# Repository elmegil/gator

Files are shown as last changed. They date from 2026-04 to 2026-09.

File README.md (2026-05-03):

"Hook's Gator" trigger (gate) sequencer.

Controls:
- tempo
- gate width (need to state range)
- step count
- swing (50% - no swing, to 70%)
- run/stop switch and gate input
- forward/backward (need to test backward with swing) switch and gate input
- reset button and gate input
- clock in + clock out (external clock is reflected on the output and overrides internal tempo)
- 1x16 or 2x8 operation -- in 1x16 both outputs reflect the same
- each step has a switch that indicates if there should be a gate out on that step or not.

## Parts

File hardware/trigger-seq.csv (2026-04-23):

Reference | Value | Footprint | Datasheet
P1 | CONN_02X05 | Connect:VASCH5x2
C2 | 10uF | Capacitors_ThroughHole:C_Radial_D5_L6_P2.5
C1 | 10uF | Capacitors_ThroughHole:C_Radial_D5_L6_P2.5
D2 | 1N4001 | Diodes_ThroughHole:Diode_DO-41_SOD81_Horizontal_RM10
D1 | 1N4001 | Diodes_ThroughHole:Diode_DO-41_SOD81_Horizontal_RM10
F2 | F_Small | Capacitors_ThroughHole:C_Disc_D7.5_P5
F1 | F_Small | Capacitors_ThroughHole:C_Disc_D7.5_P5
C3 | 100n | Capacitors_ThroughHole:C_Rect_L7_W2_P5
C5 | 100n | Capacitors_ThroughHole:C_Rect_L7_W2_P5
C6 | 100n | Capacitors_ThroughHole:C_Rect_L7_W2_P5
C7 | 100n | Capacitors_ThroughHole:C_Rect_L7_W2_P5
P8 | CONN_01X04 | My Library:MTA-156-4
U1 | LM555N | Housings_DIP:DIP-8_W7.62mm_LongPads
R2 | 100R | Resistors_ThroughHole:Resistor_Horizontal_RM10mm
RV1 | 100K | Walter Resistors:trimmer_alps-rk09k1130ah1
R1 | 15K | Resistors_ThroughHole:Resistor_Horizontal_RM10mm
C9 | 22uF | Capacitors_ThroughHole:C_Radial_D5_L11_P2.5
C4 | 100nF | Capacitors_ThroughHole:C_Rect_L7_W2_P5
U7 | TL072 | Housings_DIP:DIP-8_W7.62mm_LongPads
C8 | 100nF | Capacitors_ThroughHole:C_Rect_L7_W2_P5
C12 | 100nF | Capacitors_ThroughHole:C_Rect_L7_W2_P5
C10 | 100nF | Capacitors_ThroughHole:C_Rect_L7_W2_P5
C13 | 220uF | Capacitors_ThroughHole:C_Radial_D10_L13_P5
R3 | 4.7K | Resistors_ThroughHole:Resistor_Horizontal_RM10mm
R4 | 15K | Resistors_ThroughHole:Resistor_Horizontal_RM10mm
U8 | LM311N | Housings_DIP:DIP-8_W7.62mm_LongPads
C15 | 100nF | Capacitors_ThroughHole:C_Rect_L7_W2_P5
C14 | 100nF | Capacitors_ThroughHole:C_Rect_L7_W2_P5
R7 | 10K | Resistors_ThroughHole:Resistor_Horizontal_RM10mm
RV2 | 100K | Walter Resistors:trimmer_alps-rk09k1130ah1
R5 | 68K | Resistors_ThroughHole:Resistor_Horizontal_RM10mm
R6 | 82K | Resistors_ThroughHole:Resistor_Horizontal_RM10mm
P5 | CLOCK_MAIN | Pin_Headers:Pin_Header_Straight_2x02
P4 | CLOCK_PANEL | Socket_Strips:Socket_Strip_Straight_2x02
U2 | 4029 | Housings_DIP:DIP-16_W7.62mm_LongPads
J3 | DIRECTION | My Library:thonkiconn
SW2 | SWITCH_INV | Walter Switches:switch_100sp5
R11 | 100K | Resistors_ThroughHole:Resistor_Horizontal_RM10mm
D6 | D | Diodes_ThroughHole:Diode_DO-35_SOD27_Horizontal_RM10
Q5 | 2N3904 | TO_SOT_Packages_THT:TO-92_Inline_Narrow_Oval
R12 | 10K | Resistors_ThroughHole:Resistor_Horizontal_RM10mm
J2 | RESET | My Library:thonkiconn
SW1 | RESET | My Library:C&K_round_pushbutton
Q4 | 2N3904 | TO_SOT_Packages_THT:TO-92_Inline_Narrow_Oval
R8 | 100K | Resistors_ThroughHole:Resistor_Horizontal_RM10mm
D4 | D | Diodes_ThroughHole:Diode_DO-35_SOD27_Horizontal_RM10
R10 | 10K | Resistors_ThroughHole:Resistor_Horizontal_RM10mm
J1 | CLOCK_IN | My Library:thonkiconn
D5 | D | Diodes_ThroughHole:Diode_DO-35_SOD27_Horizontal_RM10
R9 | 100K | Resistors_ThroughHole:Resistor_Horizontal_RM10mm
U4 | 4051 | Housings_DIP:DIP-16_W7.62mm_LongPads
R16 | 10K | Resistors_ThroughHole:Resistor_Horizontal_RM10mm
U3 | 4051 | Housings_DIP:DIP-16_W7.62mm_LongPads
R15 | 10K | Resistors_ThroughHole:Resistor_Horizontal_RM10mm
Q6 | 2N3904 | TO_SOT_Packages_THT:TO-92_Inline_Narrow_Oval
R14 | 10K | Resistors_ThroughHole:Resistor_Horizontal_RM10mm
R13 | 10K | Resistors_ThroughHole:Resistor_Horizontal_RM10mm
SW3 | 3PDT | My Library:3PDT
C11 | 22n | Capacitors_ThroughHole:C_Rect_L7_W2_P5
P6 | SWITCH_PANEL | Socket_Strips:Socket_Strip_Straight_2x08
P7 | SWITCH_MAIN | Pin_Headers:Pin_Header_Straight_2x08
P2 | COUNT_PANEL | Socket_Strips:Socket_Strip_Straight_2x05
P3 | COUNT_MAIN | Pin_Headers:Pin_Header_Straight_2x05
D3 | 1N4148 | Diodes_ThroughHole:Diode_DO-35_SOD27_Horizontal_RM10
C16 | 810nF | Capacitors_ThroughHole:C_Rect_L7_W2_P5
R41 | 100K | Resistors_ThroughHole:Resistor_Horizontal_RM10mm
D7 | S1 | LEDs:LED-5MM
SW4 | SWITCH_INV | Walter Switches:switch_100sp5
D15 | 1N914 | Diodes_ThroughHole:Diode_DO-35_SOD27_Horizontal_RM10
J4 | OUT 1 | My Library:thonkiconn
SW5 | SWITCH_INV | Walter Switches:switch_100sp5
SW6 | SWITCH_INV | Walter Switches:switch_100sp5
SW7 | SWITCH_INV | Walter Switches:switch_100sp5
SW8 | SWITCH_INV | Walter Switches:switch_100sp5
SW9 | SWITCH_INV | Walter Switches:switch_100sp5
SW10 | SWITCH_INV | Walter Switches:switch_100sp5
SW11 | SWITCH_INV | Walter Switches:switch_100sp5
SW12 | SWITCH_INV | Walter Switches:switch_100sp5
SW13 | SWITCH_INV | Walter Switches:switch_100sp5
SW14 | SWITCH_INV | Walter Switches:switch_100sp5
SW15 | SWITCH_INV | Walter Switches:switch_100sp5
SW16 | SWITCH_INV | Walter Switches:switch_100sp5
SW17 | SWITCH_INV | Walter Switches:switch_100sp5
SW18 | SWITCH_INV | Walter Switches:switch_100sp5
SW19 | SWITCH_INV | Walter Switches:switch_100sp5
D16 | 1N914 | Diodes_ThroughHole:Diode_DO-35_SOD27_Horizontal_RM10
D17 | 1N914 | Diodes_ThroughHole:Diode_DO-35_SOD27_Horizontal_RM10
D18 | 1N914 | Diodes_ThroughHole:Diode_DO-35_SOD27_Horizontal_RM10
D19 | 1N914 | Diodes_ThroughHole:Diode_DO-35_SOD27_Horizontal_RM10
D20 | 1N914 | Diodes_ThroughHole:Diode_DO-35_SOD27_Horizontal_RM10
D21 | 1N914 | Diodes_ThroughHole:Diode_DO-35_SOD27_Horizontal_RM10
D22 | 1N914 | Diodes_ThroughHole:Diode_DO-35_SOD27_Horizontal_RM10
D38 | 1N914 | Diodes_ThroughHole:Diode_DO-35_SOD27_Horizontal_RM10
D37 | 1N914 | Diodes_ThroughHole:Diode_DO-35_SOD27_Horizontal_RM10
D36 | 1N914 | Diodes_ThroughHole:Diode_DO-35_SOD27_Horizontal_RM10
D35 | 1N914 | Diodes_ThroughHole:Diode_DO-35_SOD27_Horizontal_RM10
D34 | 1N914 | Diodes_ThroughHole:Diode_DO-35_SOD27_Horizontal_RM10
D33 | 1N914 | Diodes_ThroughHole:Diode_DO-35_SOD27_Horizontal_RM10
D32 | 1N914 | Diodes_ThroughHole:Diode_DO-35_SOD27_Horizontal_RM10
D31 | 1N914 | Diodes_ThroughHole:Diode_DO-35_SOD27_Horizontal_RM10
J5 | OUT 2 | My Library:thonkiconn
R34 | 1K | Resistors_ThroughHole:Resistor_Horizontal_RM10mm
R25 | 1K | Resistors_ThroughHole:Resistor_Horizontal_RM10mm
R17 | 1K | Resistors_ThroughHole:Resistor_Horizontal_RM10mm
D8 | S2 | LEDs:LED-5MM
R18 | 1K | Resistors_ThroughHole:Resistor_Horizontal_RM10mm
D9 | S3 | LEDs:LED-5MM
R19 | 1K | Resistors_ThroughHole:Resistor_Horizontal_RM10mm
D11 | S5 | LEDs:LED-5MM
R21 | 1K | Resistors_ThroughHole:Resistor_Horizontal_RM10mm
D12 | S6 | LEDs:LED-5MM
R22 | 1K | Resistors_ThroughHole:Resistor_Horizontal_RM10mm
D10 | S4 | LEDs:LED-5MM
R20 | 1K | Resistors_ThroughHole:Resistor_Horizontal_RM10mm
D13 | S7 | LEDs:LED-5MM
R23 | 1K | Resistors_ThroughHole:Resistor_Horizontal_RM10mm
D14 | S8 | LEDs:LED-5MM
R24 | 1K | Resistors_ThroughHole:Resistor_Horizontal_RM10mm
D23 | S9 | LEDs:LED-5MM
R26 | 1K | Resistors_ThroughHole:Resistor_Horizontal_RM10mm
D24 | S10 | LEDs:LED-5MM
R27 | 1K | Resistors_ThroughHole:Resistor_Horizontal_RM10mm
D25 | S11 | LEDs:LED-5MM
R28 | 1K | Resistors_ThroughHole:Resistor_Horizontal_RM10mm
D26 | S12 | LEDs:LED-5MM
R29 | 1K | Resistors_ThroughHole:Resistor_Horizontal_RM10mm
D27 | S13 | LEDs:LED-5MM
R30 | 1K | Resistors_ThroughHole:Resistor_Horizontal_RM10mm
D28 | S14 | LEDs:LED-5MM
R31 | 1K | Resistors_ThroughHole:Resistor_Horizontal_RM10mm
D29 | S15 | LEDs:LED-5MM
R32 | 1K | Resistors_ThroughHole:Resistor_Horizontal_RM10mm
D30 | S16 | LEDs:LED-5MM
R33 | 1K | Resistors_ThroughHole:Resistor_Horizontal_RM10mm
R38 | 10K | Resistors_ThroughHole:Resistor_Horizontal_RM10mm
R39 | 10K | Resistors_ThroughHole:Resistor_Horizontal_RM10mm
R36 | 10K | Resistors_ThroughHole:Resistor_Horizontal_RM10mm
Q7 | 2N3904 | TO_SOT_Packages_THT:TO-92_Inline_Narrow_Oval
R37 | 10K | Resistors_ThroughHole:Resistor_Horizontal_RM10mm
U5 | LM311N | Housings_DIP:DIP-8_W7.62mm_LongPads
U6 | LM311N | Housings_DIP:DIP-8_W7.62mm_LongPads
R35 | 10K | Resistors_ThroughHole:Resistor_Horizontal_RM10mm
R40 | 10K | Resistors_ThroughHole:Resistor_Horizontal_RM10mm
J6 | CLOCK_OUT | My Library:thonkiconn
R42 | 1K | Resistors_ThroughHole:Resistor_Horizontal_RM10mm

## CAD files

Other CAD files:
firmware/gator.X/l.obj

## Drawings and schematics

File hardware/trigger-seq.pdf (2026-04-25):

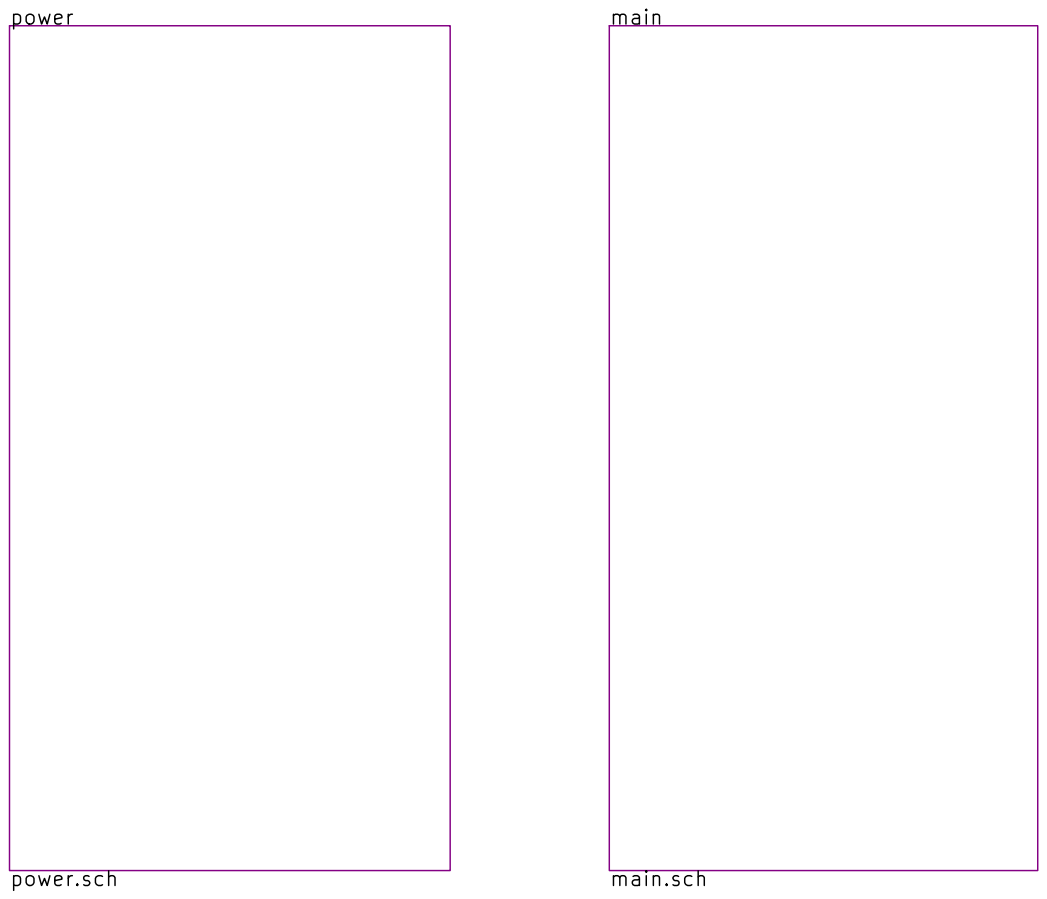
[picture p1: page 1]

simple trigger sequencer to go with the 808 boards
File: trigger-seq.sch Sheet: / Frogleg Synthesis

Id: 1/6 Title: Trigger Sequencer

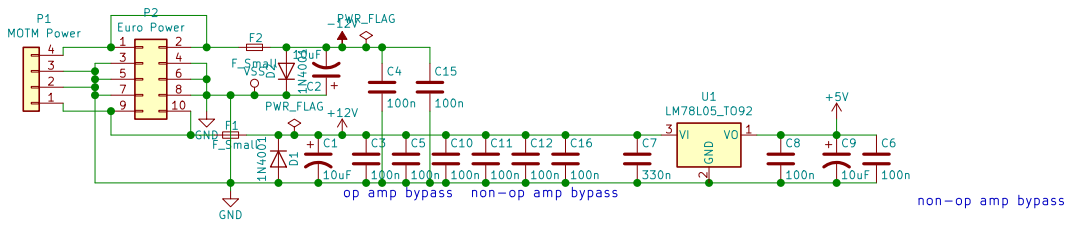
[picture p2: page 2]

100n non-op amp bypass C16

Frogleg Synthesis
Sheet: /power/
File: power.sch
Id: 2/6 Title: Voice Host

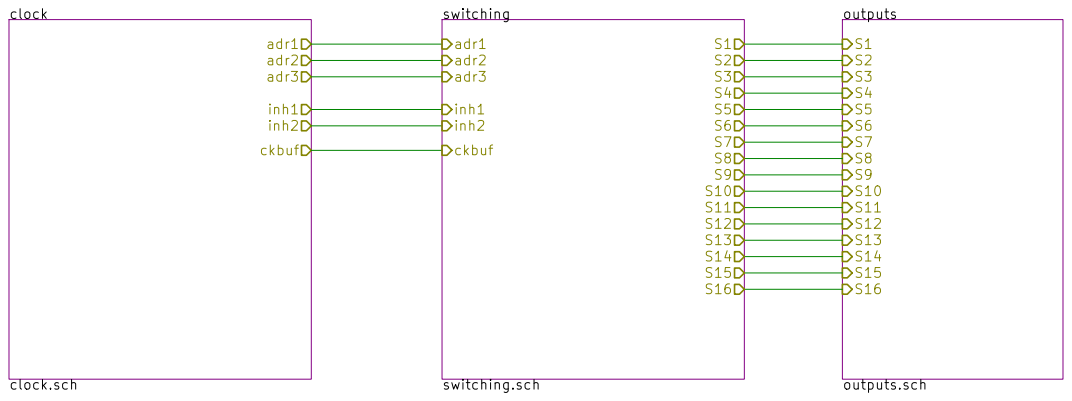
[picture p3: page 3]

Id: 3/6 Title: File: main.sch Sheet: /main/

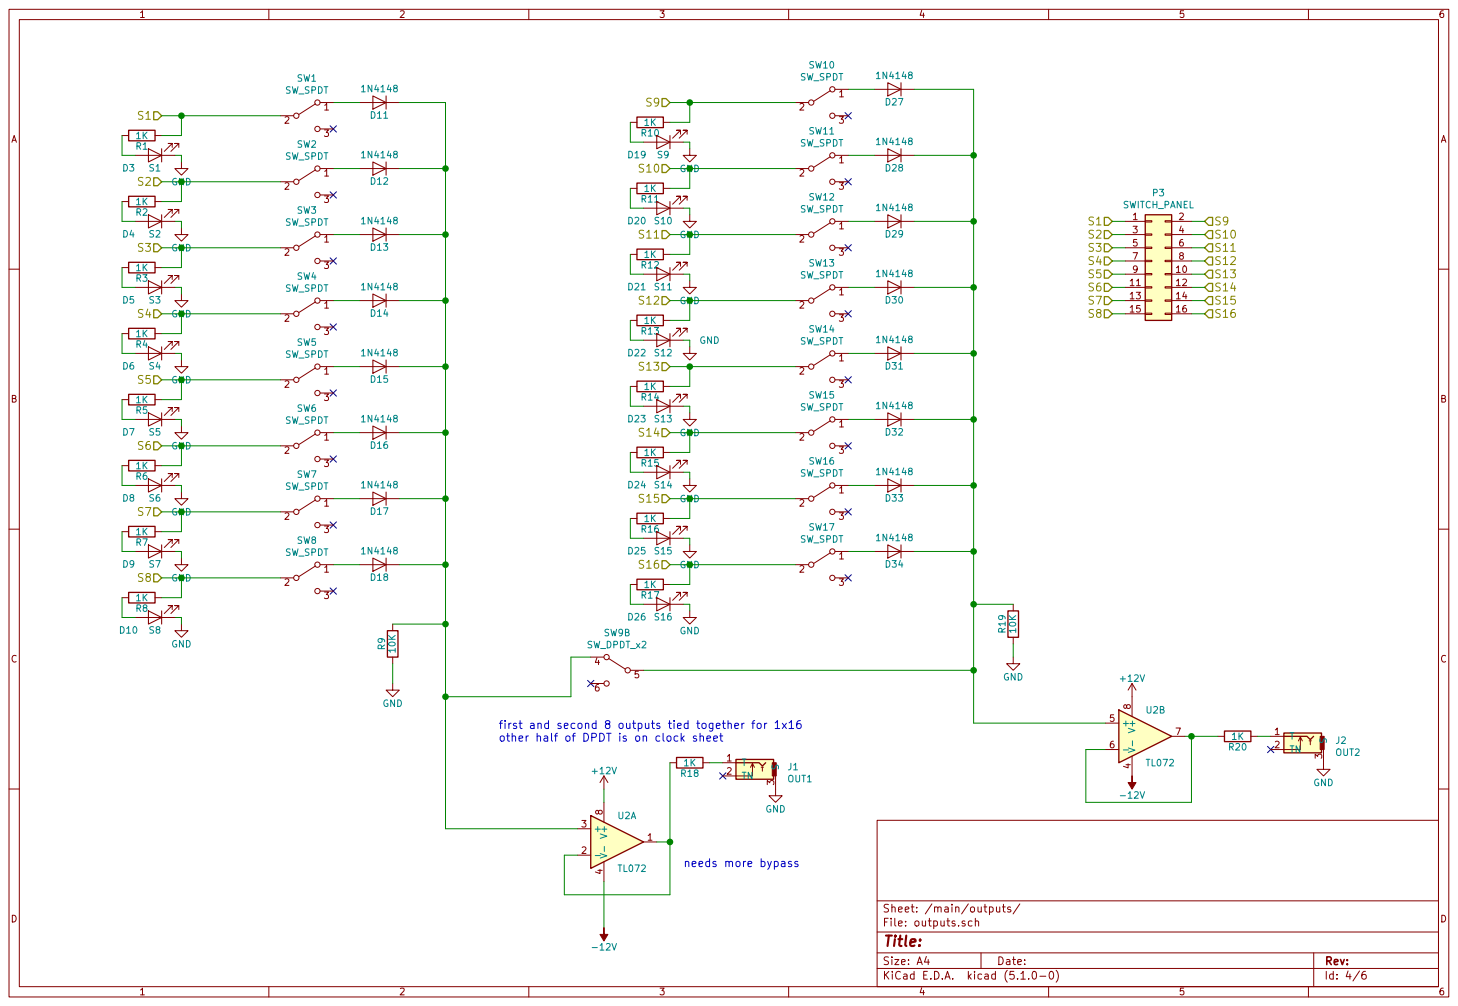
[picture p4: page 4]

first and second 8 outputs tied together for 1x16 other half of DPDT is on clock sheet

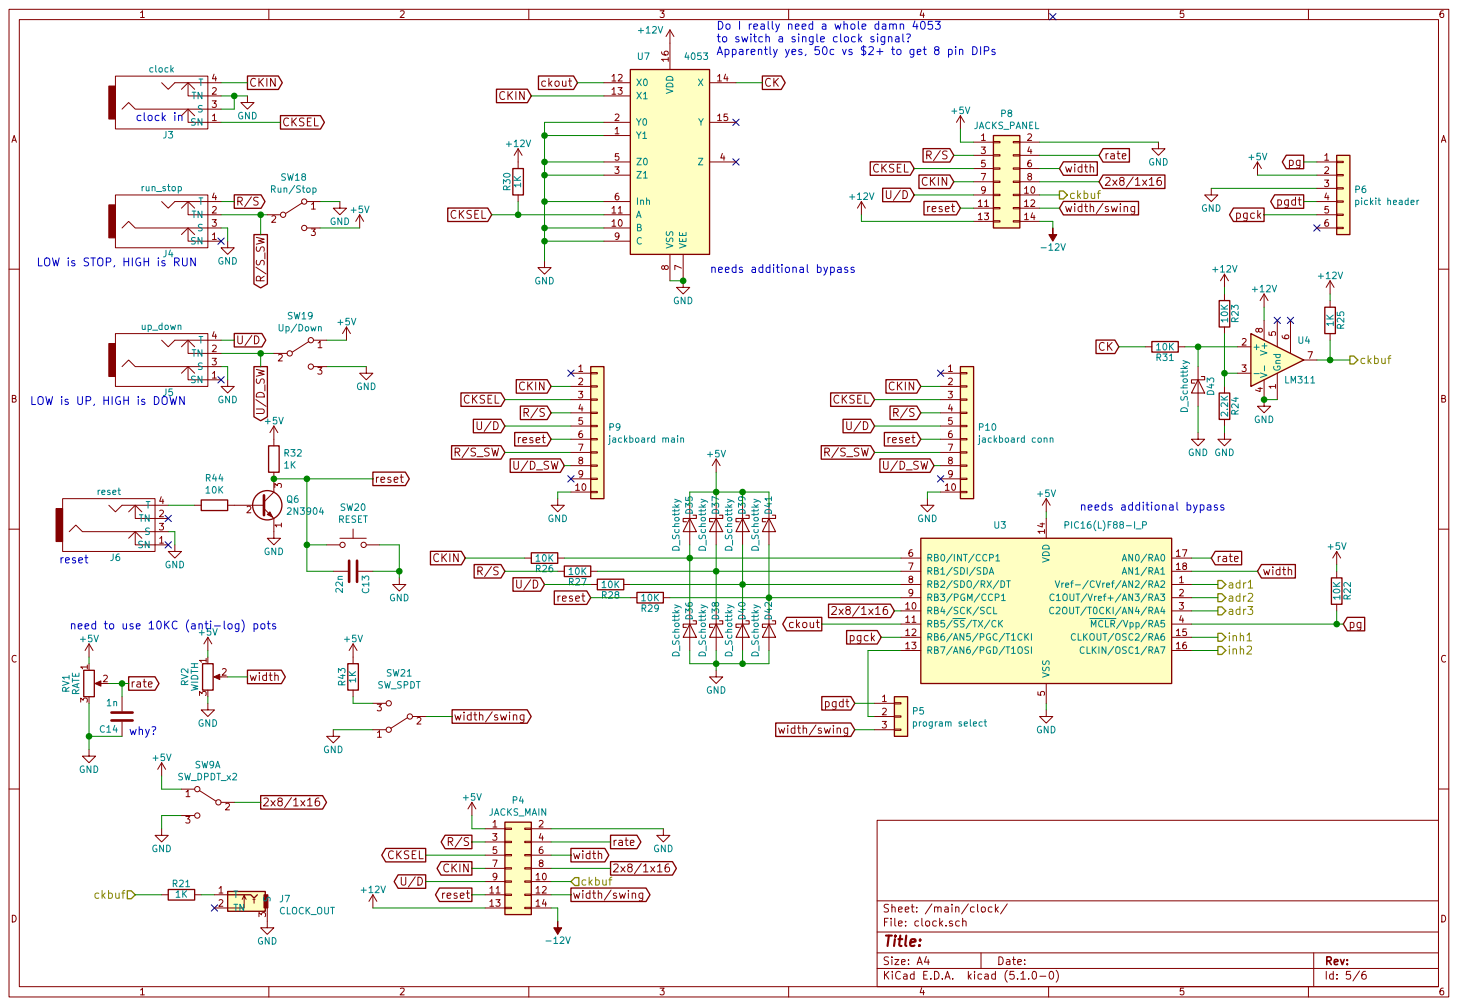
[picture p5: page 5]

+5V Do I really need a whole damn 4053
to switch a single clock signal?

Apparently yes, 50c vs $2+ to get 8 pin DIPs GND

LOW is STOP, HIGH is RUN

LOW is UP, HIGH is DOWN

5 RB0/INT/CCP1 6 RB1/SDI/SDA 7 RB2/SDO/RX/DT 8 RB3/PGM/CCP1 9 U3 PIC16(L)F88-I_P

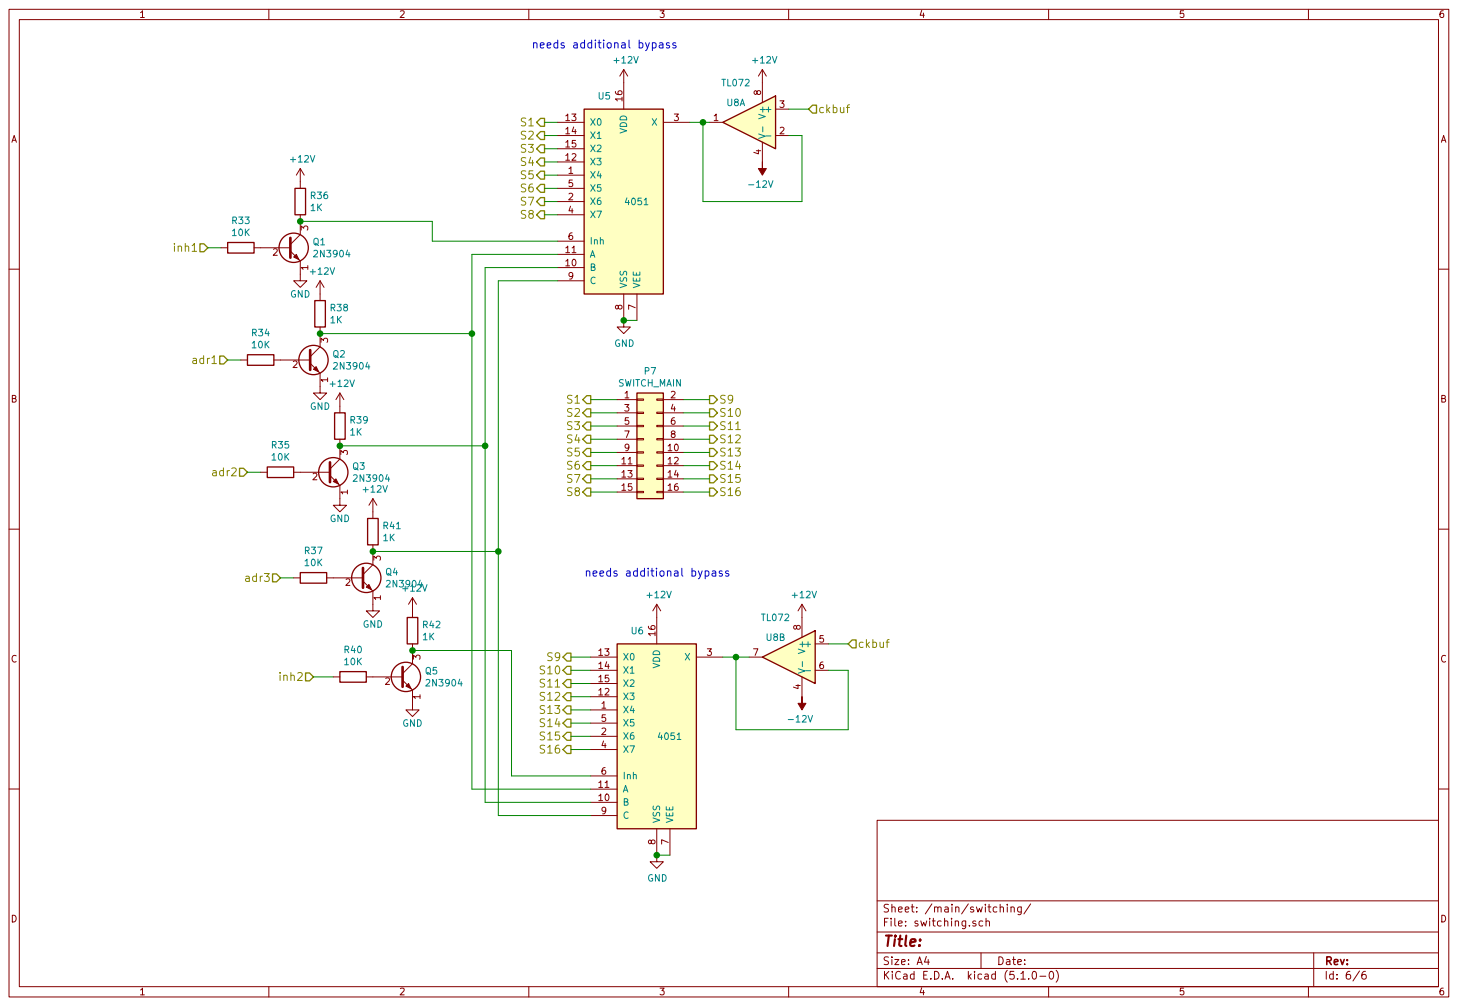
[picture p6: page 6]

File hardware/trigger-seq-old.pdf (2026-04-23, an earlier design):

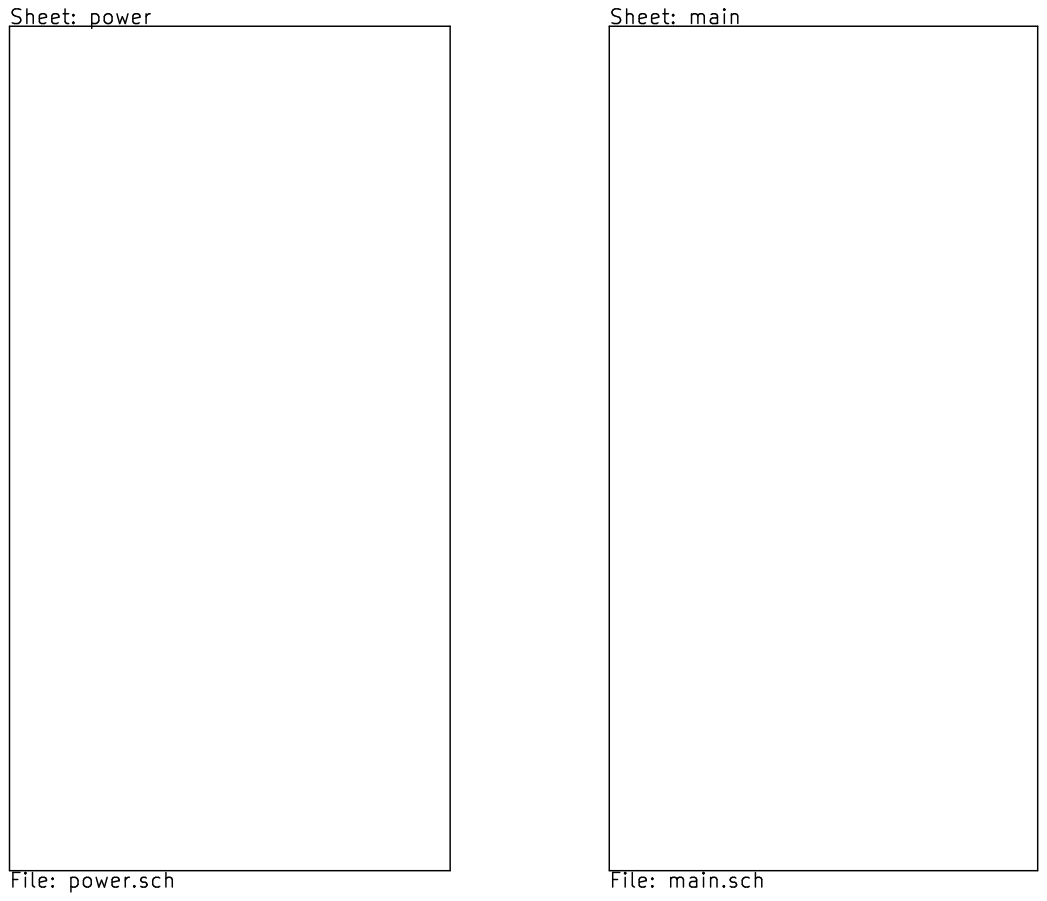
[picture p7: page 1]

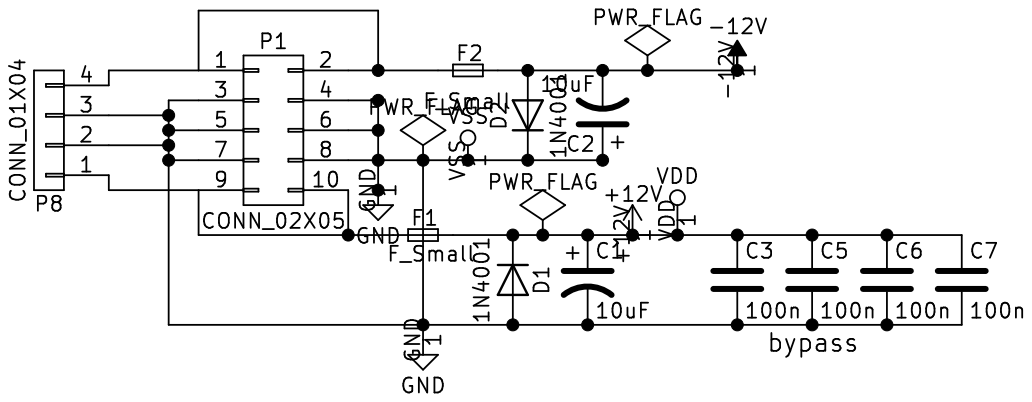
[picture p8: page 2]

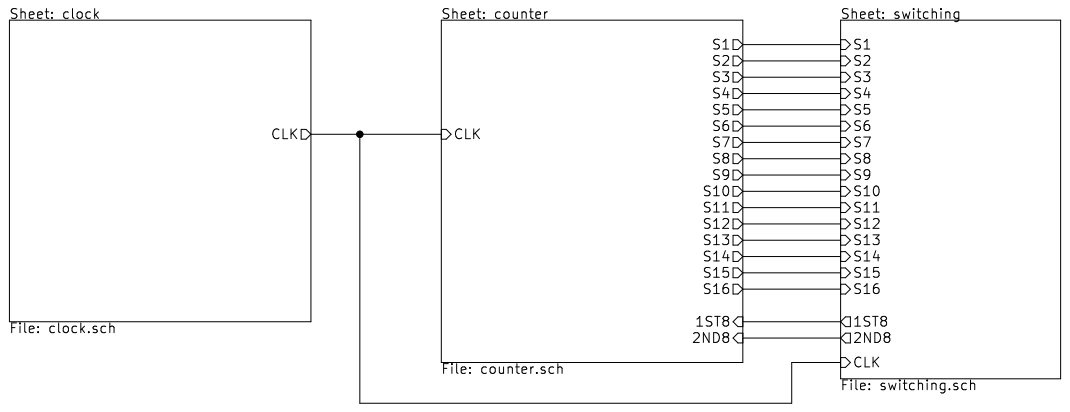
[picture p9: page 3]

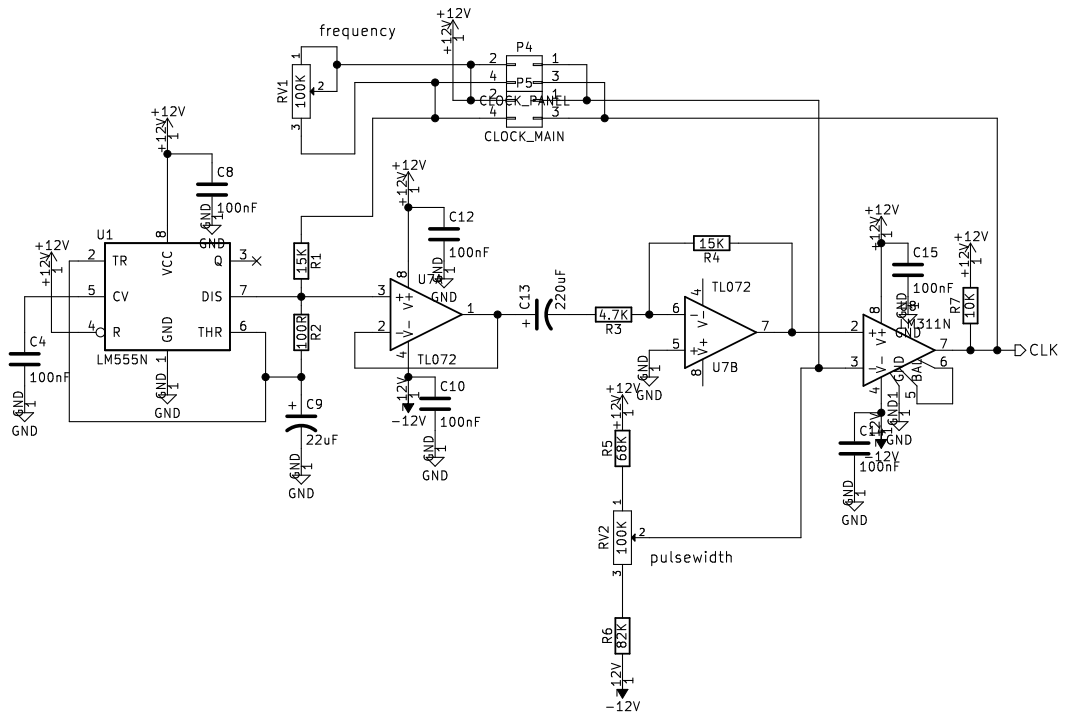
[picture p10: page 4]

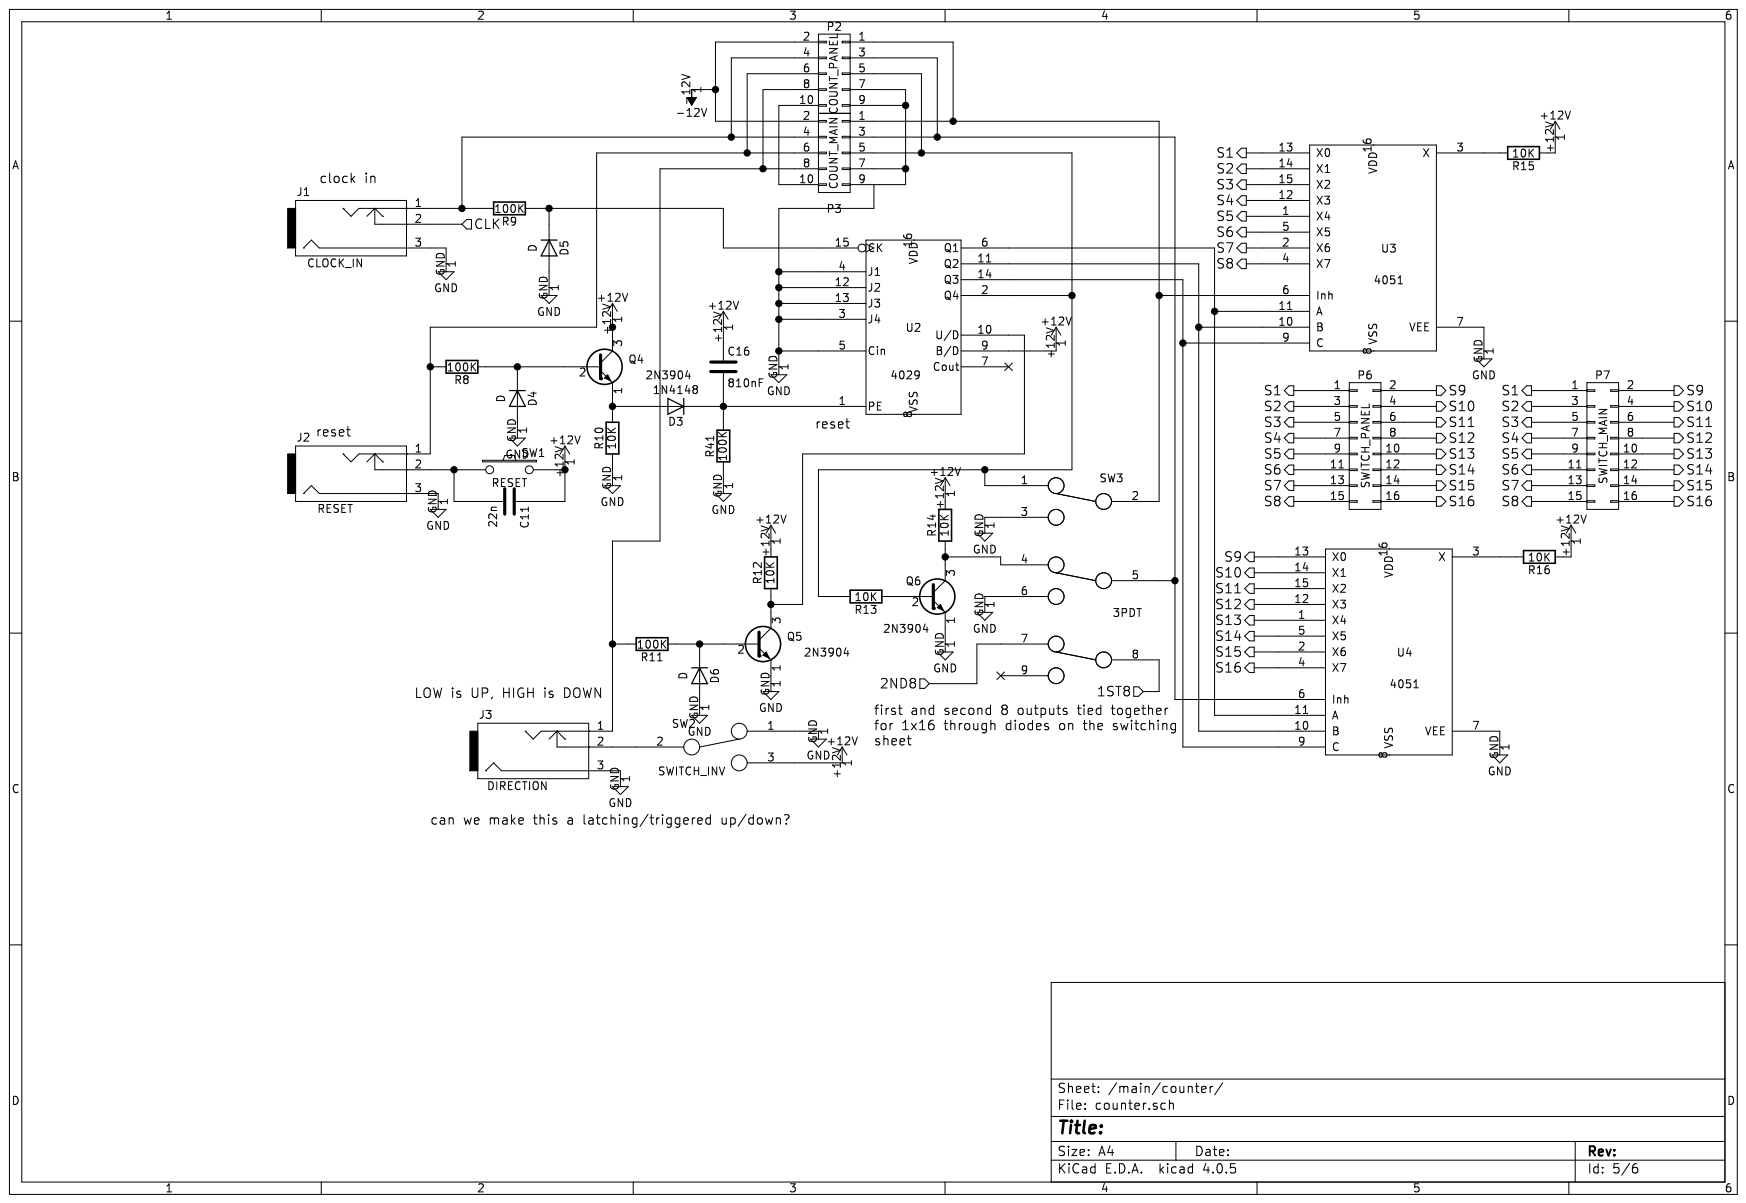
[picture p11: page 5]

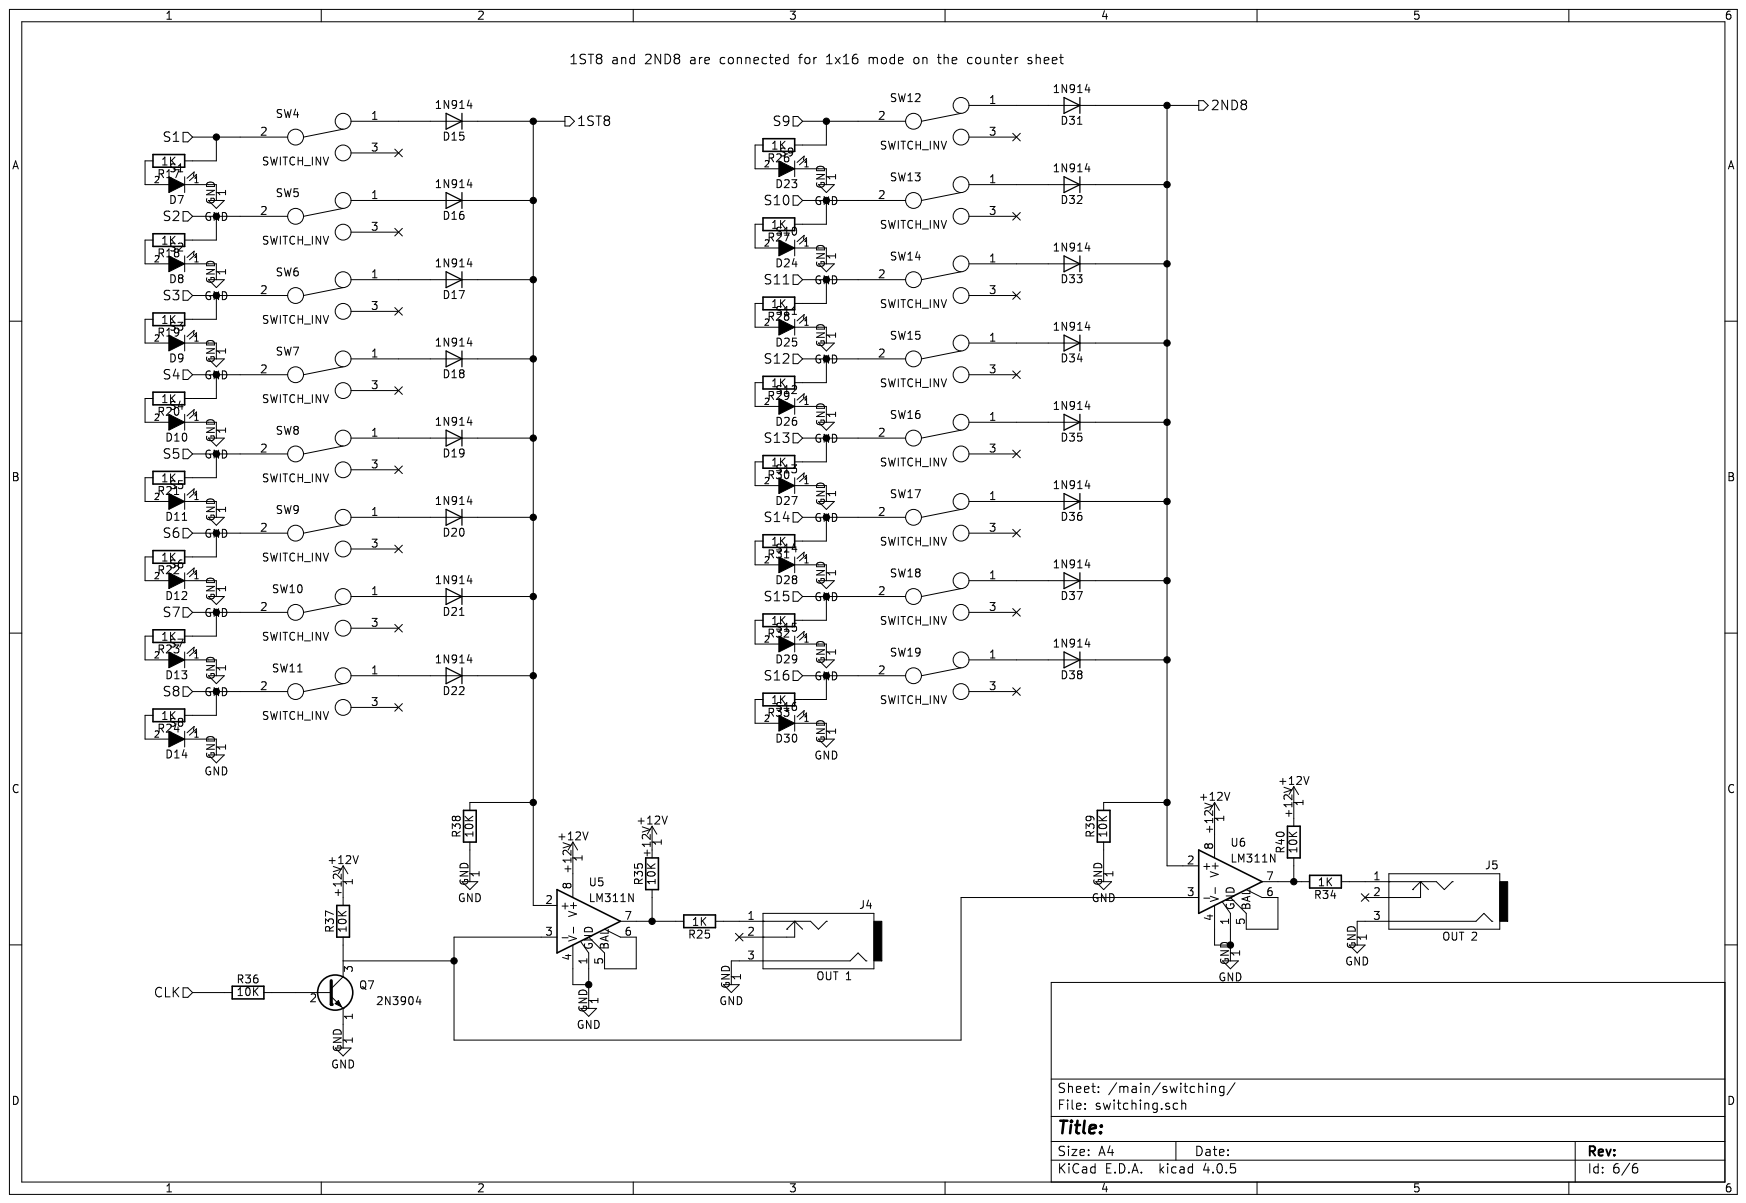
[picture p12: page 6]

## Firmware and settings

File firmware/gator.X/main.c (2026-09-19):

/*
 * File:   main.c
 * Author: petehartman
 * 
 * Hook's Gator source code: gate/trigger sequencer using PIC16F15345 (was PIC16F88)
 *
 * Created on June 12, 2018, 9:47 PM
 * Heavily revised May 23 2019
 * Even more heavily revised after May 25 2019, changing chip to get more pins
 * revised/verified for 3.0 PCB and 16F15345 starting Jun 11, 2023
 *  - implemented length of sequence 2023/06/19
 *  - swing is in progress 2023/06/20
 * revised, bugs corrected, etc with assistance of Claude 2026/04/24 - 2026/04/30
 */

// PIC16F15345 Configuration Bit Settings
// config bits set by the configuration bits tool

// CONFIG1
#pragma config FEXTOSC = OFF    // External Oscillator mode selection bits (Oscillator not enabled)
#pragma config RSTOSC = HFINT32 // Power-up default value for COSC bits (HFINTOSC with OSCFRQ= 32 MHz and CDIV = 1:1)
#pragma config CLKOUTEN = OFF   // Clock Out Enable bit (CLKOUT function is disabled; i/o or oscillator function on OSC2)
#pragma config CSWEN = ON       // Clock Switch Enable bit (Writing to NOSC and NDIV is allowed)
#pragma config FCMEN = ON       // Fail-Safe Clock Monitor Enable bit (FSCM timer enabled)

// CONFIG2
#pragma config MCLRE = OFF      // Master Clear Enable bit (MCLR pin is Master Clear function; required for ICSP); apparently NOT required for ICSP unless doing LVP?
#pragma config PWRTE = ON       // Power-up Timer Enable bit (PWRT enabled)
#pragma config LPBOREN = OFF    // Low-Power BOR enable bit (ULPBOR disabled)
#pragma config BOREN = OFF      // Brown-out reset enable bits (Brown-out reset disabled)
#pragma config BORV = LO        // Brown-out Reset Voltage Selection (Brown-out Reset Voltage (VBOR) set to 1.9V on LF, and 2.45V on F Devices)
#pragma config ZCD = OFF        // Zero-cross detect disable (Zero-cross detect circuit is disabled at POR.)
#pragma config PPS1WAY = ON     // Peripheral Pin Select one-way control (The PPSLOCK bit can be cleared and set only once in software)
#pragma config STVREN = ON      // Stack Overflow/Underflow Reset Enable bit (Stack Overflow or Underflow will cause a reset)

// CONFIG3
#pragma config WDTCPS = WDTCPS_31// WDT Period Select bits (Divider ratio 1:65536; software control of WDTPS)
#pragma config WDTE = OFF       // WDT operating mode (WDT Disabled, SWDTEN is ignored)
#pragma config WDTCWS = WDTCWS_7// WDT Window Select bits (window always open (100%); software control; keyed access not required)
#pragma config WDTCCS = SC      // WDT input clock selector (Software Control)

// CONFIG4
#pragma config BBSIZE = BB512   // Boot Block Size Selection bits (512 words boot block size)
#pragma config BBEN = OFF       // Boot Block Enable bit (Boot Block disabled)
#pragma config SAFEN = OFF      // SAF Enable bit (SAF disabled)
#pragma config WRTAPP = OFF     // Application Block Write Protection bit (Application Block not write protected)
#pragma config WRTB = OFF       // Boot Block Write Protection bit (Boot Block not write protected)
#pragma config WRTC = OFF       // Configuration Register Write Protection bit (Configuration Register not write protected)
#pragma config WRTSAF = OFF     // Storage Area Flash Write Protection bit (SAF not write protected)
#pragma config LVP = OFF        // Low Voltage Programming Enable bit (High Voltage on MCLR/Vpp must be used for programming)
// chip uses Vpp == VIHH == 8 .. 9V for programming; will also reuse the pin for clock detection

// CONFIG5
#pragma config CP = OFF         // UserNVM Program memory code protection bit (UserNVM code protection disabled)

// #pragma config statements should precede project file includes.
// Use project enums instead of #define for ON and OFF.

#include <xc.h>
#include <pic16f15345.h>

// defines for my purposes
// 4051 address pins
#define addrA RC3
#define addrB RC4
#define addrC RC5
// chip select, inhibit is active low, i.e. inh1 = 0 turns off chip 1
// actual chips are active high, but using common collector transistor drivers inverts the logic
#define inh1 RC6
#define inh2 RC7
// inputs
#define runstop RA2
#define updown RA4
#define reset RA5 
#define mode_sw RC1    // read pin for mode state
#define ckout RC0
#define intclk RC2    
#define clkpresent RA3 // doubling up on Vpp pin

// ADC acquire bytes in adcon0
// which input, "go" bit, unused, on/off for AD function
// go bit should not be done same time as on/off per data sheet
// so leaving those bits 0 until I explicitly set them
// for 16F15345, bits are different: ADGO bit is in a different place, clock source is in ADCON1
#define rate  0b00110101
#define width 0b00110001
#define steps 0b00111001
#define swing 0b00111101
#define ADGO  0b00000010

// 225 -> 256 with prescaler of 64 gives roughly 1ms resolution on timer 0
#define TM0COUNT 225
//  vvv needed for __delay functions
// 16F88 max is 8MHz, that's what this was originally coded for
// 16F15345 can go up to 32MHz, might try after getting the basics working
#define _XTAL_FREQ 8000000

// no builtin, need this in the ISR so using a macro.  Yes I know this isn't the BEST way to do it
// but I'm only ever going to call this with a single type -- signed char
#define MIN(X, Y) (((X) < (Y)) ? (X) : (Y))

// globals
unsigned int  clock0 = 0;  // has to be global for interrupt routine
unsigned int  duty = 0;    // unsigned int here, but calculations done in long to avoid overflow
unsigned int  period = 0;
signed char   row = 0;
signed char   increment = 1;
unsigned char column = 1;  // if mode is 1x16, which column are we in, 1 or 2?
unsigned char col_bits = 1; // just to start, will get assigned 1 2 or 3 later
signed char   last = 8;    // start with full 8 steps
unsigned char mode_state = 0; // 0=2x8, 1=1x16, maintained by main
signed int    offset = 0;   // "swing" will be an offset added or subtracted from period length
signed char   evenodd = 1; // evenodd keeps track of what beat this is, only odd beats get shifted


// have to bite the bullet and make a table lookup for mapping the pot curves.
// note that 1023 is the SLOW end of the pot  So while the data will still map
// 0 -> 1023, 1023 corresponds to the CCW position.
// current table calculated from $y = (($x+325)**6)/(5.85634*10**14); for x = 0 .. 1023
// numbers determined from the intersection of p = ((1023+n)**6)/10230 and p = (n**6)/2
// 6th order equation has a nice curve, 1023 is x max, 10230 is y max (roughly), 
// 0 is x min (so n + 0 in the second equation) 2 is y min (can't use y=0 for obvious reasons)
// if you want to monkey with these values, I recommend wolfram alpha, give it the two
// equations and say equation1 intersects equation2 and it will tell you the point where they intersect
//
// perl code to generate the table:
//
//    #!/usr/bin/perl
//    #
//    # qd to generate Gator input lookup table
//    #
//    print "const int curve[1024] = {";
//    foreach $i (0 .. 63) {
//            foreach $j (0 .. 15) {
//                    $x = ($i * 16 + $j);
//                    $y = (($x+324)**6)/(5.85634*10**14); # 324 gives better result at the high end
//                    printf "%5d,", $y;
//            }
//            print "\n                         ";
//    }
//    print "};\n";

// defines the response curve of the speed pot; values are just clock ticks
// at the fast end probably need to clamp at 8

const unsigned int curve[1024] = {    8,    8,    8,    8,    8,    8,    8,    8,    8,    8,    8,    8,    8,    8,    8,    8,
                             8,    8,    8,    8,    8,    8,    8,    8,    8,    8,    8,    8,    8,    8,    8,    8,
                             8,    8,    8,    8,    8,    8,    8,    8,    8,    8,    8,    8,    8,    8,    8,    8,
                             8,    8,    8,    8,    8,    8,    8,    8,    8,    8,    8,    8,    8,    8,    8,    8,
                             8,    8,    8,    8,    8,    8,    8,    8,    8,    8,    8,    8,    8,    8,    8,    8,
                             8,    8,    8,    8,    8,    8,    8,    8,    8,    8,    8,    8,    8,    8,    9,    9,
                             9,    9,    9,    9,    9,   10,   10,   10,   10,   10,   10,   10,   11,   11,   11,   11,
                            11,   11,   12,   12,   12,   12,   12,   12,   13,   13,   13,   13,   13,   13,   14,   14,
                            14,   14,   14,   15,   15,   15,   15,   15,   16,   16,   16,   16,   17,   17,   17,   17,
                            17,   18,   18,   18,   18,   19,   19,   19,   19,   20,   20,   20,   20,   21,   21,   21,
                            21,   22,   22,   22,   23,   23,   23,   23,   24,   24,   24,   25,   25,   25,   26,   26,
                            26,   27,   27,   27,   27,   28,   28,   29,   29,   29,   30,   30,   30,   31,   31,   31,
                            32,   32,   32,   33,   33,   34,   34,   34,   35,   35,   36,   36,   36,   37,   37,   38,
                            38,   39,   39,   40,   40,   40,   41,   41,   42,   42,   43,   43,   44,   44,   45,   45,
                            46,   46,   47,   47,   48,   48,   49,   49,   50,   50,   51,   52,   52,   53,   53,   54,
                            54,   55,   56,   56,   57,   57,   58,   59,   59,   60,   61,   61,   62,   63,   63,   64,
                            65,   65,   66,   67,   67,   68,   69,   69,   70,   71,   72,   72,   73,   74,   75,   75,
                            76,   77,   78,   78,   79,   80,   81,   82,   82,   83,   84,   85,   86,   87,   87,   88,
                            89,   90,   91,   92,   93,   94,   95,   96,   96,   97,   98,   99,  100,  101,  102,  103,
                           104,  105,  106,  107,  108,  109,  110,  111,  113,  114,  115,  116,  117,  118,  119,  120,
                           121,  122,  124,  125,  126,  127,  128,  129,  131,  132,  133,  134,  136,  137,  138,  139,
                           141,  142,  143,  145,  146,  147,  149,  150,  151,  153,  154,  155,  157,  158,  160,  161,
                           162,  164,  165,  167,  168,  170,  171,  173,  174,  176,  177,  179,  181,  182,  184,  185,
                           187,  189,  190,  192,  194,  195,  197,  199,  200,  202,  204,  206,  207,  209,  211,  213,
                           215,  216,  218,  220,  222,  224,  226,  228,  230,  232,  233,  235,  237,  239,  241,  243,
                           245,  247,  250,  252,  254,  256,  258,  260,  262,  264,  267,  269,  271,  273,  275,  278,
                           280,  282,  284,  287,  289,  291,  294,  296,  299,  301,  303,  306,  308,  311,  313,  316,
                           318,  321,  323,  326,  329,  331,  334,  336,  339,  342,  344,  347,  350,  353,  355,  358,
                           361,  364,  367,  369,  372,  375,  378,  381,  384,  387,  390,  393,  396,  399,  402,  405,
                           408,  411,  415,  418,  421,  424,  427,  431,  434,  437,  440,  444,  447,  450,  454,  457,
                           461,  464,  468,  471,  475,  478,  482,  485,  489,  493,  496,  500,  504,  507,  511,  515,
                           519,  522,  526,  530,  534,  538,  542,  546,  550,  554,  558,  562,  566,  570,  574,  578,
                           582,  587,  591,  595,  599,  604,  608,  612,  617,  621,  626,  630,  634,  639,  644,  648,
                           653,  657,  662,  667,  671,  676,  681,  686,  690,  695,  700,  705,  710,  715,  720,  725,
                           730,  735,  740,  745,  750,  755,  761,  766,  771,  776,  782,  787,  792,  798,  803,  809,
                           814,  820,  825,  831,  837,  842,  848,  854,  860,  865,  871,  877,  883,  889,  895,  901,
                           907,  913,  919,  925,  931,  938,  944,  950,  956,  963,  969,  976,  982,  989,  995, 1002,
                          1008, 1015, 1021, 1028, 1035, 1042, 1048, 1055, 1062, 1069, 1076, 1083, 1090, 1097, 1104, 1111,
                          1119, 1126, 1133, 1140, 1148, 1155, 1163, 1170, 1177, 1185, 1193, 1200, 1208, 1216, 1223, 1231,
                          1239, 1247, 1255, 1263, 1271, 1279, 1287, 1295, 1303, 1311, 1319, 1328, 1336, 1344, 1353, 1361,
                          1370, 1378, 1387, 1396, 1404, 1413, 1422, 1431, 1440, 1448, 1457, 1466, 1475, 1485, 1494, 1503,
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
                         };


void Init_PIC(void) { // commented out bits are from previous part number 16F88
//    OSCCON     = 0b01111100; //osc  8 MHz, primary sys clock, frequency tsable, osc mode defined by FOSC above
    OSCFRQ     = 0b00000011; // 011 is 8MHz clock // 12MHz is 100, 16MHz is 101, 32MHz is 110
    PMD0       = 0b00000110; // disable modules at a higher level; disable NVM & CLKRef
    PMD1       = 0b10000110; // disable NCO, TMR1 & TMR2
    PMD2       = 0b01000111; // disable DAC1, CMP2, CMP1, ZCD (zero cross detection)
    PMD3       = 0b00111111; // disable PWMs and CCPs
    PMD4       = 0b11010001; // disable UARTS, MSSP (serial port), CWG (complementary waveform)
    PMD5       = 0b00011110; // disable config logic cells
    CCP1CON    = 0b00000000; // disable comparator modules
    CCP2CON    = 0b00000000; // disable comparator modules
    SSP1CON1   = 0b00000000; // disable Serial port (bit 5 = 0) (used for I2C/SPI)
    INTCON     = 0b00000001; // disable interrupts; set interrupt to rising edge
    TRISA      = 0b00111100; //port directions; outputs are 0 inputs are 1; bit3=RA3/clkpresent input
    WPUA       = 0b00111100; // weak pull ups for the input bits; RA3 pulled high = no cable
    WPUC       = 0b00000100; // RC2 is clock in, pull it up as well
    TRISB      = 0b11110000; 
    TRISC      = 0b00000110; 
    ANSELA     = 0b00000000; //analog select 0 == digital, 1 == analog for A, bits 3,6,7 unused
    ANSELB     = 0b11110000; // for B, bits 0-3 are unused
    ANSELC     = 0b00000000;
    ADCON0     = 0b01000000; // channel sel RC0, disable AD
    ADCON1     = 0b11010000; // rt just, Fosc/8, Vdd as the reference -- note that recommended values are minimum of Fosc/X where X is the MHz of the osc
    PORTA      = 0b00000000; // start up ports at all 0 
    PORTB      = 0b00000000;
    PORTC      = 0b00000000;
}

void Init_interrupts(void) {
    INTCON    &= 0b01111111; // ensure GIE is cleared
    T0CON0     = 0b10000000;  // enable, 8-bit timer, post scaler of 1:1
    T0CON1     = 0b01000110;  // clock source Fosc/4, sync to Fosc/4, prescaler 1:64
    PIE0      &= 0b11001111;  // disable PIE interrupts timer and IOC
    PIR0      &= 0b11001111;  // clear the flags
    TMR0L      = TM0COUNT;
    PIE0      |= 0b00100000; // enable timer0 interrupt <<<
    IOCCP      = 0b00000100; // RC2 positive edge detect
    IOCCF      = 0b00000000; // clear any pending IOC flags
    PIE0      |= 0b00010000; // enable IOC interrupts ; was  0b10000000 which is incorrect for this model!!
    INTCON    |= 0b10000000; // enable global interrupts
}


static void advance_step(void) {
    evenodd = (evenodd == 1) ? -1 : 1;
    clock0 = 0;
    row += increment;
    if (mode_state == 0) {          // 2x8 mode
        if ((row >= last) || (row <= -1)) {
            row = (row >= last) ? 0 : (last - 1);
        }
    } else if (column == 1) {       // 1x16 mode, 1st column
        if (row >= MIN(8,last)) {
            column = (last <= 8) ? 1 : 2;
            row = 0;
        } else if (row <= -1) {
            column = (last <= 8) ? 1 : 2;
            row = (last <= 8) ? (last - 1) : (last - 9);
        }
    } else {                        // 1x16 mode, 2nd column
        if ((8 + row) >= last) {
            column = 1;
            row = 0;
        } else if (row <= -1) {
            column = 1;
            row = 7;
        }
    }
    col_bits = (mode_state == 0) ? 3 : column;
}

// old test code, restoring to work with the interrupt issues

void Pulse_bit(unsigned char loc, unsigned char mybit, unsigned char column) {
    loc = (~loc) & 0x07; // what bit position 0 - 7 aka LEDs 1-8; inverting for transistor drivers, masking AFTER inversion
    column &= 0x03;
    mybit &= 0x01;
    PORTC = (unsigned char)(((loc)<<3) | ((column)<<6) | mybit ); // set location as RC3,4,5, inhibit is RC6,7, clock is mybit
    __delay_ms(50);
    PORTC = (unsigned char)(((loc)<<3) | ((column)<<6) );
    __delay_ms(50);
}




void __interrupt() ISR(void) {
    if ((PIE0 & PIR0 & 0b00010000) != 0) { // IOC interrupt: external clock rising edge on RC2 ; originally 0b01000000 which is wrong
        if (IOCCF & 0b00000100) {  // specifically checking for RC2
            if (reset == 1 && runstop == 1 && !clkpresent) {  // clkpresent is active low
                advance_step();
                // I'm using transistor buffers which invert the signals
                // so we pre-invert -- ~row -- before adding to PORTC
                PORTC = (unsigned char)(((~row & 0x07)<<3) | ((col_bits & 0x03)<<6)) | 1;
            }
            IOCCF &= ~0b00000100;
        }
        PIR0 &= ~0b00010000;
    }
    if ((PIE0 & PIR0 & 0b00100000) != 0) { // timer 0 interrupt
        TMR0L = TM0COUNT;
        clock0++;
        if (reset == 1) { // 1 is "not reset"; reset processed outside run/stop so reset works while stopped
            if (runstop == 1) {
                if (clkpresent) { // internal clock: advance step on period
                    if (clock0 >= (unsigned int)((int)period+offset)) {
                        advance_step();
                    }
                }
                // external clock: step already advanced in IOC handler above
                unsigned char portc_base = (unsigned char)(((~row & 0x07)<<3) | ((col_bits & 0x03)<<6));
                PORTC = portc_base | (clock0 <= duty ? 1 : 0);  // 1 is gate on, 0 is gate off
            } else { // not running, no clocking!
                col_bits = (mode_state == 0) ? 3 : column;
                PORTC = (unsigned char)(((~row & 0x07)<<3) | ((col_bits & 0x03)<<6) | 1);   // leave it lit so we know where we are
                clock0 = 10200;
            }
        } else {  // held in reset, not lit
            PORTC = (unsigned char)(((~row & 0x07)<<3) | ((column & 0x03)<<6) | 0);
            clock0 = 10200; // 10200 will always be > period
            if (updown == 1) { // backward
                if (mode_state == 1 && last > 8) {
                    row = last - 8;
                    column = 2;
                } else {
                    row = last;
                    column = 1;
                }
            } else { // forward
                row = -1;
                column = 1;
            }
            evenodd = 1;
        }
        PIR0 &= ~0b00100000;
    }
    INTCON |= 0b10000000; // set GIE
}

// see page 231 of datasheet (increasing a bit, hoping to get more stable output)
#define AQtime  8
#define TADtime 15

int Acquire(char adcon) {  
    ADCON0 = adcon;      // don't turn on Go bit same time as turn on the ADC
    __delay_us(AQtime);  
    adcon |= ADGO;   
    ADCON0 = adcon;
    __delay_us(TADtime);  // 
    // loop until "go" bit returns to 0
    while ((ADCON0>>1)&1); // wait for DONE#
    return ((((int)ADRESH)<<8) + (int)ADRESL);
}
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
void main(void) {
    Init_PIC();
    Init_interrupts();
    for (;;) {
        unsigned int new_period = curve[Acquire(rate)]; // pots are wired with +5V at ccw and gnd at cw
        unsigned int new_duty = (unsigned int)(((unsigned long)(1023 - Acquire(width)) * (unsigned long)new_period)/1023);
        // (swing / 2.5) maps 0 - 409, * (period / 1023) == offset; re-arranging fractions gives (swing * period / 2558)
        signed int new_offset = (signed int)((unsigned long)(1023 - Acquire(swing)) * (unsigned long)new_period / 2558); 
        // precompute adjusted duty for both swing phases outside INTCON -- slow multiply/divide
        // inside the interrupt-disabled block was causing ISR jitter that affected tempo
        signed int pos_offset = new_offset;
        signed int neg_offset = -new_offset;
        unsigned int adj_duty_pos = (unsigned int)((signed int)new_duty + (signed int)((signed long)new_duty * pos_offset / (signed int)new_period));
        unsigned int adj_duty_neg = (unsigned int)((signed int)new_duty + (signed int)((signed long)new_duty * neg_offset / (signed int)new_period));
        // is this block causing the jittery response to external clock?
        // additionally, duty and ext clock don't play well together, need to resolve
        INTCON &= 0b01111111; // block interrupts for multi-byte operations
        period = new_period;
        if (evenodd == 1) {
            offset = pos_offset;
            duty = adj_duty_pos;
        } else {
            offset = neg_offset;
            duty = adj_duty_neg;
        }
        signed int eff_period = (signed int)period + offset;
        if ((signed int)duty < 4) duty = 4;
        if ((signed int)duty > (eff_period - 4)) duty = (unsigned int)(eff_period - 4); // minimum 1ms pulse either end with variable duty
        INTCON |= 0b10000000; // unblock interrupts
        // digital inputs
        increment = (updown == 1) ? -1 : 1;

        unsigned char new_mode = mode_sw;
        if (new_mode != mode_state) {
            if (new_mode == 1) column = 1;  // entering 1x16, always start in column 1
            mode_state = new_mode;          // note we don't move the *row*
        }
        // handle steps 
        last = (signed char)(((1023 - Acquire(steps))>>6)+1); // without +1 it never gets to 8 steps
        if (mode_state  == 0) {
            last = last>>1;
        }
    }
}






//void Set_bits(unsigned char col, unsigned char value) {
//    unsigned char current;
//    for (unsigned char bitnum=0; bitnum<8; bitnum++) {
//        current = ((value)>>bitnum) & 0b00000001; // shift to the bit then strip it to just the bit
//        PORTC = (unsigned char)((current)|((col)<<6)|((~bitnum)&0x7)<<3);
//    }
//}

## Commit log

2026-04-23 initial checkin of old project
    [clock-processing.sch, clock.sch, counter.sch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]
2026-04-25 replaced old hardware files with the most recent ones tracking CLAUDE.md AI files used in revising the project
    [clock-2018-06-08-23-49-19.sch, clock-2019-01-04-11-33-57.sch, clock-2019-01-04-11-34-14.sch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]
2026-04-30 update with my first cut at swing; scope looks good, need further testing
2026-04-30 fixes to swing; pre-clock-in
    [main.c]
2026-04-30 latest fixes to prevent obvious tempo skew depending on width + duty
    [main.c]
2026-04-30 add gitattributes to stop identifying KiCad as HTML
2026-05-03 expanding panel to 18HP so the controls are less crowded
    [trigger-seq-panel.kicad_pcb, trigger-seq.kicad_pcb]
2026-05-03 cleaning up
    [clock-2019-01-04-11-33-57.sch, clock-2019-01-04-11-34-14.sch, clock-2019-01-04-11-35-06.sch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]
2026-05-03 more cleanup
    [clock-processing.sch, clock.sch, main.sch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]
2026-05-17 wider panel + better spacing v3.3
    [trigger-seq-panel.kicad_pcb, trigger-seq.kicad_pcb]
2026-05-30 update for version 3.3, slight tweaks to v3.2 which has now passed smoke test.
    [trigger-seq-panel.kicad_pcb, trigger-seq.kicad_pcb]
2026-06-03 adjusting panel layout (increasing vertical distance of pots, compressing vertical distance of switches, centering 1x16/2x8 switch)
    [power.kicad_sch, trigger-seq-front-panel.kicad_pcb, trigger-seq-panel.kicad_pcb]
2026-09-19 updates to correct firmware to use clock in detection; MCLRE=OFF, corrected bit locations for IOC interrupts. updates to schematics/layout
    [clock.kicad_sch, outputs.kicad_sch, power.kicad_sch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]
2026-09-19 updates to schematic properties, nips and tucks
    [clock.kicad_sch, main.kicad_sch, outputs.kicad_sch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]
